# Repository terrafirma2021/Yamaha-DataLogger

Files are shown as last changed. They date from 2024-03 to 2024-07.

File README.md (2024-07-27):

### Yamaha DataLogger
ESP32 s3 BLE Yamaha Datalogger

#### Description:
- The Yamaha DataLogger is an ESP32-S3 based device designed to convert k-line data into Canbus ODB2 standard, using ELM327 emulation. 
 Enabling compatibility with apps like RaceChrono, Realdash, and Torque. 
- Now displays PIDS via OLED screen. 
- Now handles automatic gear ratio tuning via BLE Serial "Gears", (using gipro gear indicators learn function approach). Place bike on centre stand and cycle though the gears 

#### updates:
- Migrated NVS to spiffs
- gear ratios persist on cold boot / auto load on startup
- added simple temrinal menu via serial/ble
- All serial/ble serial commands are simultaneously mirrored.
- General tidy up
- Migrated send/response commands

#### Added Files:
- Added Ecu Emulator for testing
- Added Torque app PID.csv
- Wokwi PCB Design
- My custom PCB build
- L9637d pinout
- Realdash XML (Plug and play)
- racechrono.rcz file
- 3d Printed Case STL + Photos
- 3D printed case with switch mount (switch can be found below):
- https://www.amazon.co.uk/dp/B01N367QLZ

#### Added OLED Support:
- 0.96" I2C

#### Supported PIDs:
- RPM
- Speed
- Error code
- Coolant Temp
- Gear
- MCU Temp
- CPU Freq
- Ram Free
- Top Speed
- MCU Uptime seconds

#### Requirements:
To build this project, you will need the following components:
- L9637D
- <strike>510 pull-up resistor</strike> Not needed for RX
- Level conversion components
- Due to ESP32 startup time, an external power supply switch will be required to enable esp32 to start before the ecu! This saves re-writing the codebase.

#### Additional Information:
- It's possible to pozi-tap the loom for other sensor data not sent via the k-line.
- Wokwi circuit design: https://wokwi.com/projects/391712730296045569
- Thingverse link here: https://www.thingiverse.com/thing:6560376

#### Big thanks to:
- [TriB](https://github.com/HerrRiebmann) For the L9637D's and LOTS of wise advice from an ECU VET :) 
- The Dude Discord: @skydiving123 For Schooling me alot :P  \o/
- [Unexpected Maker:](https://esp32s3.com) for the Feather S3 and support
- [RealDash](https://realdash.net/index.php)
- [Race Chrono](https://racechrono.com)

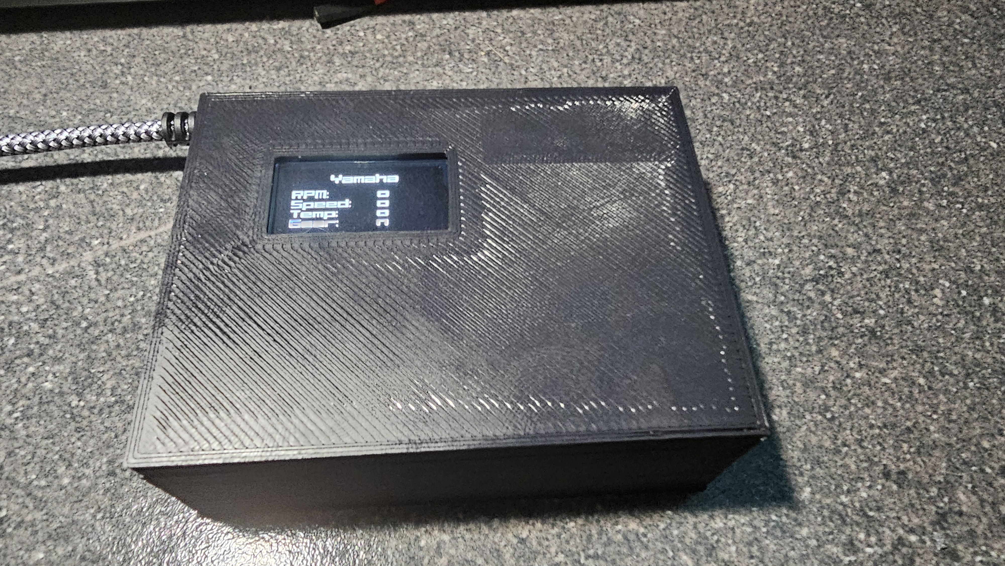
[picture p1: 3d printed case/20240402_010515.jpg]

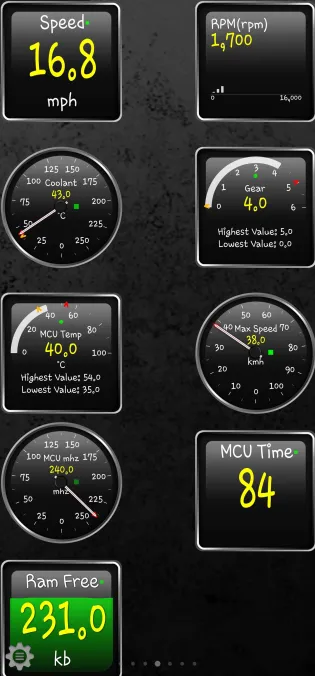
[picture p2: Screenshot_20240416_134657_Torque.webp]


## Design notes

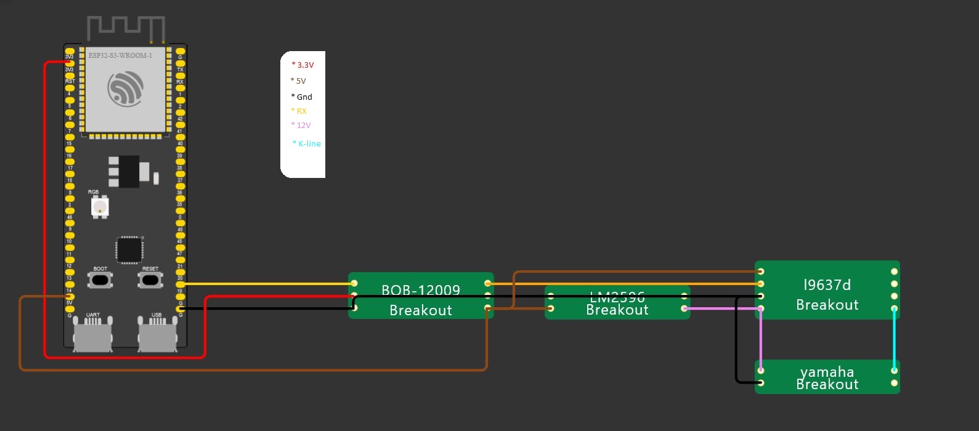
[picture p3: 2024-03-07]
wokwi_schematic.JPG

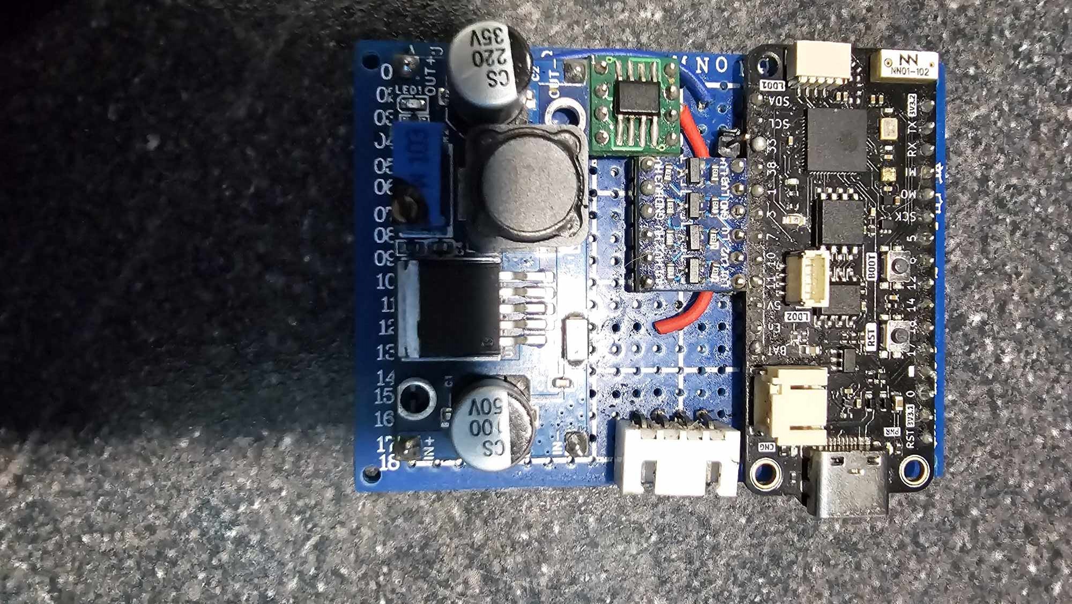
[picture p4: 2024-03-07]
My_PCB.jpg

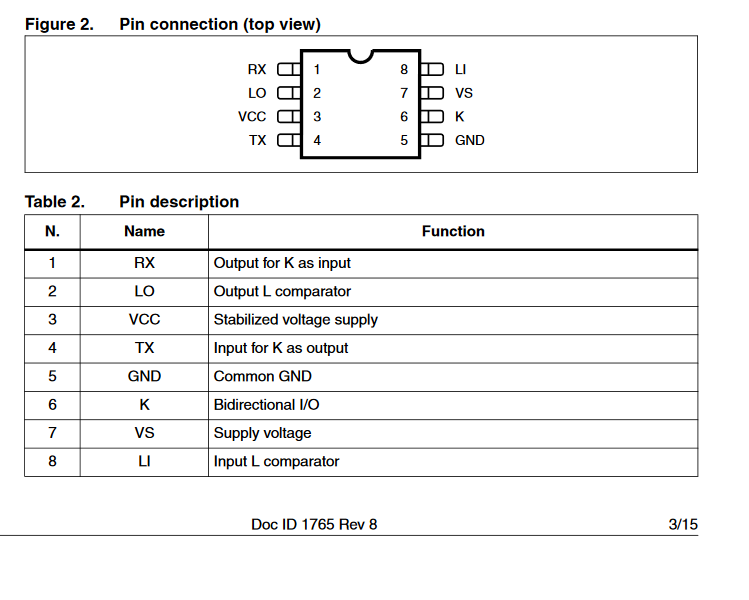
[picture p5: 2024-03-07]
L9637d.PNG

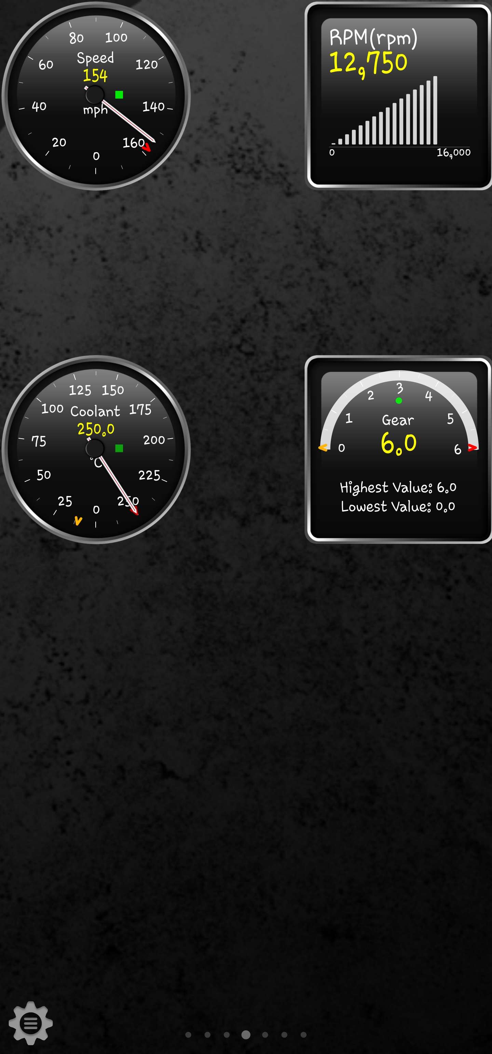
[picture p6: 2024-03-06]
Screenshot_20240306_113752_Torque.jpg

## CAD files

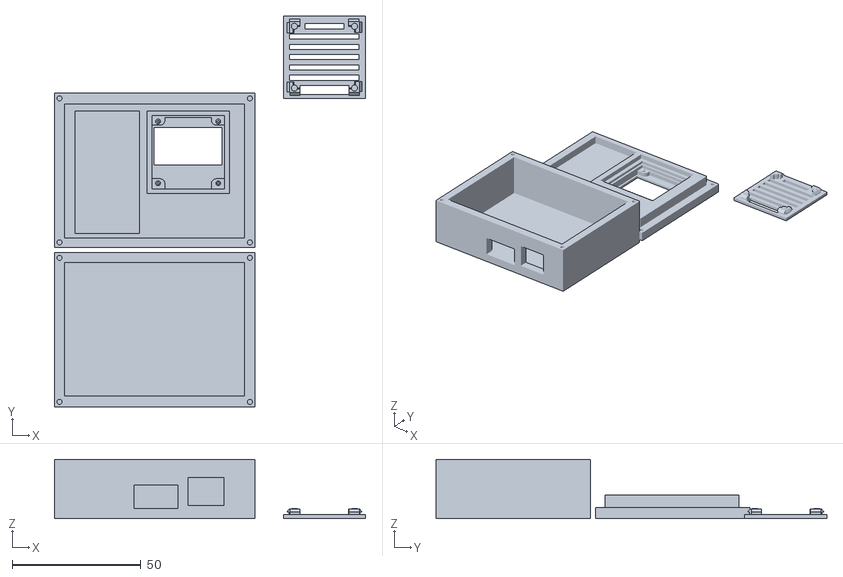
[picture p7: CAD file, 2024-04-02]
3d printed case/YDS Box.stl
121.0 x 152.0 x 23.0

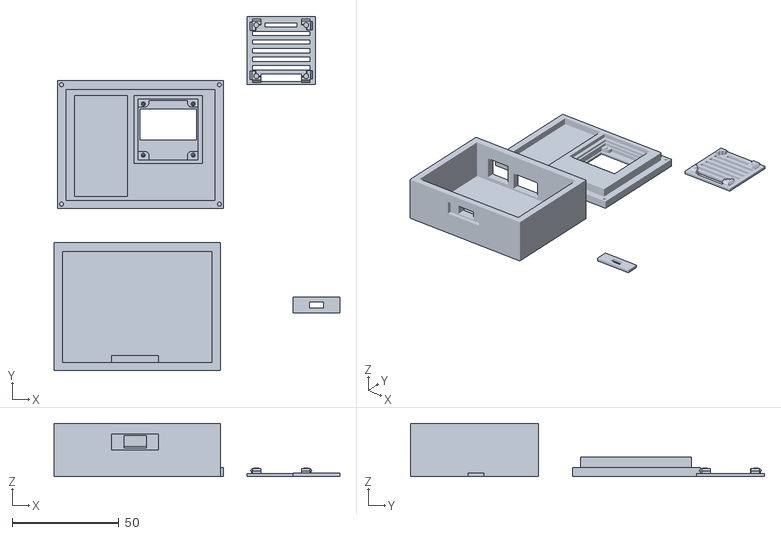
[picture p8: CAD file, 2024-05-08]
YDS BOX v3.stl
134.0 x 166.0 x 25.0

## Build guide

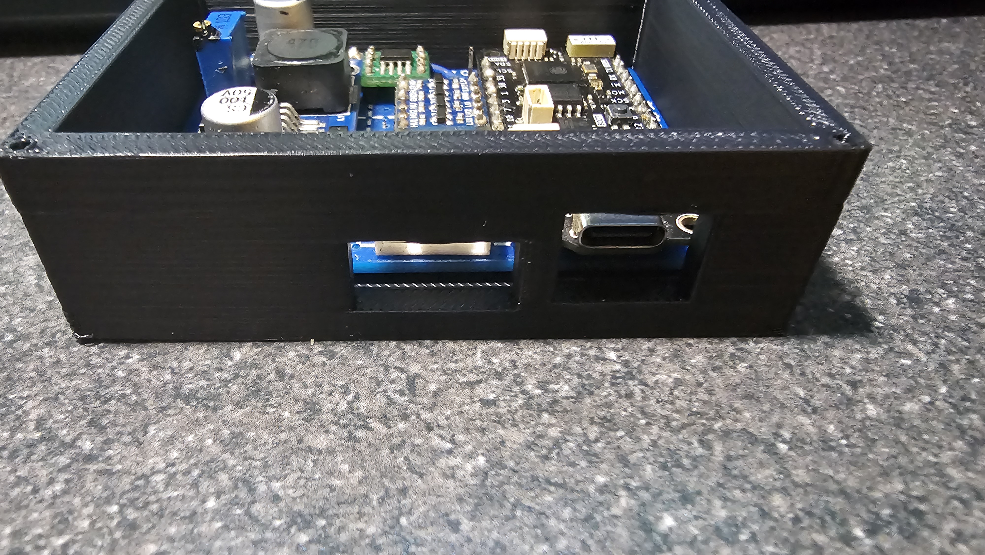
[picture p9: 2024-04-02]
3d printed case/20240402_002836.jpg

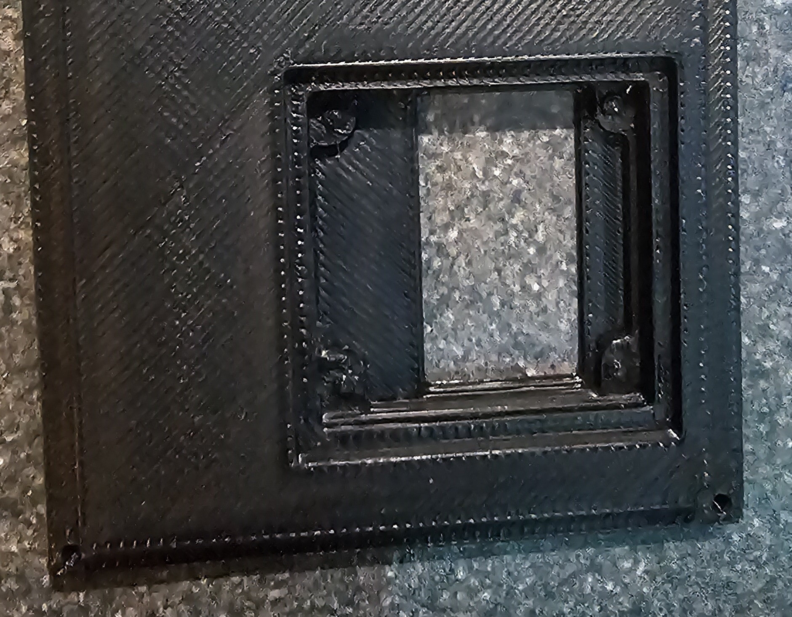
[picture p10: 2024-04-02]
3d printed case/20240401_235949.jpg

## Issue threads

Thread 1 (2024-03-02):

Schema to setup project

slowas, 2024-03-02:
Hey, I' am very intresting in your project can' you share schematic to setup this code?

terrafirma2021, 2024-03-05:
Hi yes, I will make a schematic soon, I am currently finishing up on my code.

I intend to rewrite the code to support a USB KKL Cable, (which I started from) meaning that any device with a USB host will natively be able to work from the KKL cable. This will help others who may not be able to solder, to plug in a cable :)

terrafirma2021, 2024-03-07:
@slowas Please see my main repo,, i have attached a wokwi schematic with colour coding for you. Here is the URL to the Wowki design, please be aware that I have adjusted the pinout order for clear understanding. When you build your own design, only cross over the data lines once!
https://wokwi.com/projects/391712730296045569

Closed 2024-03-07.

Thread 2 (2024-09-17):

Can't connect to ECU

VovaN60, 2024-09-17:
Hello Dear,

I don't see any contacts in your profile.
Sorry but that's why i am creating an issue.

I am working on GPS datalogger project for a few years now. And trying to adapt it to Yamaha protocol.
Tried alot with no success. Need your support.

Kindly contact me.
vovenracer@gmail.com

terrafirma2021, 2024-09-21:
HI, please upload a photo of your pcb, i will help you

terrafirma2021, 2025-03-09:
Hi, closing this issue as i have not heard back in some time, thanks

Closed 2025-03-09.

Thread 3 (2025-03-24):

Not quite pulling the right data from the packets

threepotMR2, 2025-03-24:
Firstly this is amazing! Thank you for putting this on github, its wonderful tool for the Yamaha k line.

There are loads of kit cars with the yamaha R1 engine in them, if this works I'm sure there will be other guys wanting to get this built as it should pull speed, rpm etc into racechrono. I want to also implement out getting some 0-5v analogue inputs working for TPS and wideband AFR which should be very straight forward.

I've got all the hardware running - k line adapter, the level shifter etc - that was a bit of scoping fun!! Turns out the level shifters I'd bought were not pick and placed correctly.

And it sort of works, its logging, its bluetoothing etc. I'm nearly there but.......

I think there is something not right with the packet interpretation, maybe its differences of bike - this is on a 2010 YZF-R1.

The coolant value is getting mixed up with another value, it jumps from the correct value to something else.

Here is a video of the debug PID and debug RX (which is amazing that you've built the whole menu system etc!!), and the torque pro screen.

https://www.youtube.com/watch?v=PzoZdSJurxI

I'd love it if you can shed any light on it?

Thanks, Matt

threepotMR2, 2025-03-24:
Right, I've done a proper K line log... I built a little old arduino nano like this:-

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

Very simple, just 2 resistors and an optocoupler, that lets us RX data off the k-line.

Here is the log, its just ignition on, then I start and idle it, then rev it, obviously I can see the second byte is an RPM value.

[full log from k line.txt](https://github.com/user-attachments/files/19438185/full.log.from.k.line.txt)

Then I was thinking about your project, the hardware is vastly over complicated I think, it could be done just like this:-

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

Which would sit on a very small pcb just like this very easily:-

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

terrafirma2021, 2025-04-12:
HI, thanks for the updated, information, its nice to see others pick up on the project.

Its Interesting to see an alt to the Yamaha protocol,

I know there is a v1 and a v2 dash protocol for the Yamaha,

assuming that the 5 byte protocol is used ( you should also be able to check with sigrok to confirm)

the protocol is always dash request, then ecu returns,

Interesting to see the 0A request, but it may well be that the dash is requesting more information than just rpm,vss, error code, coolant temp.

When you enter into diag mode, you will see this behaviour when in a D_ sub menu section, where the menu case is returned, then you will see the value of the menu case.

i believe i have posted sigrok sniffs of the diag menu and the main menu.

your video actually appears to be doing the same approach somewhat, which is why you are seeing ( mis reads)

terrafirma2021, 2025-04-12:
01 17 00 00 42 59
05 17 00 00 2C 43
0C 17 00 00 23 3A
0D 16 00 00 01 17

05, 0c,0d are a different type of poll which i have not seen before

threepotMR2, 2025-04-12:
0C 17 00 00 "23" 3A = this is Throttle position

I have tried to alter the way your buffer handling works in your source code.

I have tried to make the buffer 6 bytes long instead, then make different "if" statements for packets that start with a different byte.

But my programming ability is poor and I have not managed to make anything that works.

terrafirma2021, 2025-04-12:
if you go into the diag menu and sniff from there the TPS value, you will know the % to byte ratio,

this is how i worked out the coolant temp sensor

this will also allow you to decode the other values to know what they are

by cycling the diag menu, you will obtain and decode the missing values from the other frames friend

threepotMR2, 2025-04-12:
TPS is easy:-

0C 16 0 0 23 39 = 14%
0C 16 0 0 3F 55 = 25%
0C 17 0 0 83 9A = 51%
0C 2C 0 0 AC D8 = 67%
0C 51 0 0 B4 5 = 70%
0C 65 0 0 A9 0E = 66%
0C 74 0 0 6E E2 = 43%
0C 8E 0 0 2B B9 = 17%
0C 89 0 0 23 AC = 14%

0 to FF = 0 to 256 = 0% to 100%

But your programming of the main.cpp....

All you do is handle the last 5 bytes of a frame, you never look at the first byte.

I have tried to change your buffer to 6 bytes, then have some if statements on the first byte.

#define ECU_BUFFER_SIZE 5

then....

else if (isIMMOHandled)
  {
    **// Ensure buffer does not exceed 5 bytes
    if (buffer.size() >= 5)
    {**
      buffer.erase(buffer.begin());
    }
    buffer.push_back(receivedByte);

    **// Process only when buffer is exactly 5 bytes**
    if (buffer.size() == 5)
    {
      bool allZero = std::all_of(buffer.begin(), buffer.end(), [](uint32_t i)
                                 { return i == 0; });

      if (!allZero)
      {
        t_buffer_item sum = std::accumulate(buffer.begin(), buffer.end() - 1, 0);
        if (sum == buffer.back())
        {
          alignedFrame(buffer);
          buffer.clear(); // Clear the buffer for the next frame
        }
      }
    }

I am totally failing to change your code to handle the packed correctly because I am a stupid idiot LOL!

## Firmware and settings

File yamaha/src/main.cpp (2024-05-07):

#include <Arduino.h>
#include <elm327command.h>
#include <BLE.h>
#include <gear.h>
#include <spifffs.h>
#include <responsecommand.h>
#include <vector>
#include <unordered_map>
#include "esp_timer.h"
#include "LCD.h"
#include <Adafruit_GFX.h>
#include <Adafruit_SSD1306.h>
#include <U8g2lib.h>
#include <iostream>
#include <string>
#include <Wire.h>
#include <numeric>
#include <SPI.h>
#include <SPIFFS.h>


// Define L9637D Pins
#define YAM_TX 1
#define YAM_RX 38

// Debug Pins
/// #define YAM_TX 12
// #define YAM_RX 33

// Define SDA and SCL pins
#define MY_SCL_PIN 15
#define MY_SDA_PIN 16

// Debug Level
extern bool Debug_RX;
extern bool Debug_TX;
extern bool Debug_PIDS;
extern bool Debug_YAM;
bool DisableBikeOff_Flag = false;

// BLE Connected bool
extern bool clientConnected;

// Time thresholds and timeouts
uint32_t Time = esp_timer_get_time() / 1000;
const uint16_t BIKE_OFF_TIMEOUT_TIMER = 5000; // 5 seconds in microseconds
uint32_t lastByteTime = 0; 

// BLE Timers
static uint32_t lastSendTimeUartTX = 0;
static uint32_t lastSendTimeUartRX = 0;
static uint32_t lastSendTimeElmTX = 0;
static uint32_t lastSendTimeElmRX = 0;
const uint16_t sendIntervalUartTX = 1;
const uint16_t sendIntervalUartRX = 2;
const uint16_t sendIntervalElmTX = 3;
const uint16_t sendIntervalElmRX = 4;

// Magic numbers
const byte DIAG_START_BYTE = 0xCD;

// Buffer sizes
#define VEHICLE_SPEED_RAW_BUFFER_SIZE 8
#define ECU_BUFFER_SIZE 5

// Yamaha RX Buffers
using t_buffer_item = uint8_t;
using t_buffer = std::vector<t_buffer_item>;
byte Vehicle_Speed_Raw_Buffer[VEHICLE_SPEED_RAW_BUFFER_SIZE];
byte ECU_Buffer[ECU_BUFFER_SIZE];

// Immo discarded bytes
static uint32_t discardedBytesCount = 0;

// Buffer indices and time variables
byte VehicleSpeedRawBufferIndex = 0;
byte ECUBufferIndex = 0;
byte IMMOIndex = 0;

// Immo flags
bool is3E = false;
bool isIMMOHandled = false;

// ECU Mode
bool NormalData = false;
bool frameEndDetected = false;
bool diagMenu = false;

// Gears
uint8_t gear_speed = 0;
uint16_t gear_rpm = 0;
bool Gear_Speed_Ready = false;
bool Gear_RPM_Ready = false;
extern bool gearLearning;
extern bool ratioReset;
extern std::vector <float> constRatios;

// Top Speed
byte MaxSpeed = 0;

// BLE Arrays
std::queue<std::string> MyCallbacks::bleUartRxQue;
std::queue<std::string> MyCallbacks::bleElmRxQueue;

// PIDS
uint16_t RPM_PID;        // RPM * 50 = RAW
uint8_t Speed_PID;       // RAW km/h
uint8_t Coolant_PID;     // Temp = -30
uint8_t Error_PID;       // Error code
uint8_t Gear_PID = 0;    // RAW 
uint8_t Temp_PID;        // MCU Temp C
uint8_t CPU_PID;         // CPU Freq mhz
uint8_t RAM_Free_PID;    // Free Ram kb
uint8_t Max_Speed_PID;   // Max Speed Reached
uint16_t MCU_Uptime_PID; // Seconds

// Function declarations
void setup();
void loop();
void mainTime();
void YamahaRX();
void processIMMOSequence(t_buffer &buffer, t_buffer_item receivedByte);
void alignedFrame(const t_buffer &buffer);
void handleDiagData(const t_buffer &buffer);
void handleNormalData(const t_buffer &buffer);
void sendResponse(const std::string &message);
void serialRX();
extern void receiveResponse(std::string message);
void handleBikeOffCondition();
void calculateRPM(t_buffer_item rpmByte);
void calculateVehicleSpeed(t_buffer_item speedByte);
void extractErrorCode(t_buffer_item Error);
void calculateCoolantTemp(t_buffer_item Temp);
void maximumSpeed();
void updateMcuPidValues();
void debugPIDS();
void toUpperCaseInPlace(std::string &str);
void trimInPlace(std::string &str);
extern void gears();
extern void menu(std::string command);
void bleTimers();
extern void loadSpiffRatios();


// Setup
void setup()
{
  Serial.begin(115200);
  Serial1.begin(16040, SERIAL_8N1, YAM_RX, YAM_TX);
  Serial.println("Yamaha ELM327 Datalogger");
  Serial.print("MCU Temperature: ");
  Serial.print(temperatureRead());
  Serial.println(" °C");
  Serial.print("CPU Frequency: ");
  Serial.print(ESP.getCpuFreqMHz());
  Serial.println(" MHz");
  Serial.print("Free Heap: ");
  Serial.print(ESP.getFreeHeap());
  Serial.println(" bytes");
  Serial.print("Max Alloc Heap: ");
  Serial.print(ESP.getMaxAllocHeap());
  Serial.println(" bytes");
  Wire.begin(MY_SDA_PIN, MY_SCL_PIN);
  u8g2.begin();
  MyCallbacks *myCallbacks = new MyCallbacks();
  bool success = Device::getInstance().start(myCallbacks);
  if (!success)
  {
    sendResponse("Failed to start BLE");
  }
  if (!SPIFFS.begin())
  {
    sendResponse("SPIFFS mount failed");
    return;
  }
  // Init the Gear ratios from the spiffs
  loadSpiffRatios();
  menu("MENU");
}

void loop()
{
  mainTime();
  bleTimers();
  handleBikeOffCondition();
  YamahaRX();
  displayData();
  serialRX();
  debugPIDS();
  updateMcuPidValues();
  gears();
}

void mainTime(){
  Time = esp_timer_get_time() / 1000;
}

void YamahaRX()
{
  static t_buffer buffer;

  if (!Serial1.available())
  {
    return;
  }

  // Update lastByteTime with esp_timer_get_time()
  lastByteTime = esp_timer_get_time() / 1000;

  // Read a byte from Serial1
  t_buffer_item receivedByte = Serial1.read();

if (Debug_YAM)
{
    std::stringstream ss;
    ss << "Yam RX: " << std::setw(2) << std::setfill('0') << std::hex << static_cast<int>(receivedByte);
    // Get the string representation without the "0x" prefix
    std::string output = ss.str().substr(2);
    sendResponse(output);
}


  // Check and handle the first byte of the IMMO sequence immediately
  if (!is3E && receivedByte == 0x3E)
  {
    is3E = true;
    buffer.push_back(receivedByte);
    sendResponse("Starting IMMO sequence.");
    return;
  }

  if (is3E && !isIMMOHandled)
  {
    // Continue handling the IMMO sequence
    processIMMOSequence(buffer, receivedByte);
  }
  else if (isIMMOHandled)
  {
    // Ensure buffer does not exceed 5 bytes
    if (buffer.size() >= 5)
    {
      buffer.erase(buffer.begin());
    }
    buffer.push_back(receivedByte);

    // Process only when buffer is exactly 5 bytes
    if (buffer.size() == 5)
    {
      bool allZero = std::all_of(buffer.begin(), buffer.end(), [](uint32_t i)
                                 { return i == 0; });

      if (!allZero)
      {
        t_buffer_item sum = std::accumulate(buffer.begin(), buffer.end() - 1, 0);
        if (sum == buffer.back())
        {
          alignedFrame(buffer);
          buffer.clear(); // Clear the buffer for the next frame
        }
      }
    }
  }
}

void processIMMOSequence(t_buffer &buffer, t_buffer_item receivedByte)
{
  // Push the received byte into the buffer
  buffer.push_back(receivedByte);

  if (buffer.size() == 61)
  {

    if (buffer.back() == 0xCD)
    {
      diagMenu = true; // Diag menu init
      buffer.clear();
      sendResponse("Diag start initiated.");
    }
    else
    {
      buffer.clear();
    }

    isIMMOHandled = true;
    sendResponse("Normal start initiated.");
  }
}

void alignedFrame(const t_buffer &buffer)
{
  // First, ensure that the buffer size is as expected.
  if (buffer.size() != 5)
  {
    return;
  }

  if (diagMenu)
  {
    handleDiagData(buffer);
  }
  else
  {
    handleNormalData(buffer);
  }
}

void handleDiagData(const t_buffer &buffer)
{
  sendResponse("Diag menu!");
}

void handleNormalData(const t_buffer &buffer)
{

  maximumSpeed();

  if (buffer.size() != 5)
  {
    return;
  }

  calculateRPM(buffer[0]);
  calculateVehicleSpeed(buffer[1]);
  extractErrorCode(buffer[2]);
  calculateCoolantTemp(buffer[3]);
}

void sendResponse(const std::string &message)
{
  // Print the message
  Serial.println(message.c_str());

  // Check for empty command
  if (message.length() == 0)
  {
    Serial.println("Empty command received.");
    return; // Exit if the command is empty
  }

  Device::getInstance().bleUartQue(message);
}

std::string serialRXBuffer;  // Buffer to accumulate characters

void serialRX() {
    // Check if the serial connection is still active
    if (!Serial) {
        return;
    }

    if (Serial.available() > 0) {  // Check if there is data to process
        char ch = Serial.read();  // Read one character from the serial

        if (ch == '\n') {  // Check if the character is a newline
            if (!serialRXBuffer.empty()) {
                receiveResponse(serialRXBuffer);  // Process the accumulated input
                serialRXBuffer.clear();  // Clear the buffer after processing
            }
        } else {
            serialRXBuffer += ch;  // Add character to buffer if not newline
        }
    }
}

void handleBikeOffCondition()
{
  // Early return if the bike off condition handling is disabled or lastByteTime is zero
  if (DisableBikeOff_Flag || lastByteTime == 0)
  {
    return;
  }
      // Get the current time in microseconds
  uint64_t timeElapsed = Time - lastByteTime; // Calculate time elapsed since the last byte received

  if (timeElapsed > BIKE_OFF_TIMEOUT_TIMER)
  {
    // Reset flags and variables related to bike off condition
    is3E = false;
    isIMMOHandled = false;
    NormalData = false;
    frameEndDetected = false;
    diagMenu = false;
    ECUBufferIndex = 0;
    lastByteTime = 0;
    Gear_PID = 0;
    Coolant_PID = 0;
    RPM_PID = 0;
    Speed_PID = 0;
    Error_PID = 0;
    // Reset Gear
    ratioArray.clear();
    sendResponse("\nBike Off Detected");
  }
}

void calculateRPM(t_buffer_item rpmByte)
{

  uint8_t RPM = rpmByte;

  // Assign the RPM value directly to RPM_PID and gear_rpm.
  RPM_PID = RPM * 50; // Correct up to 12500
  gear_rpm = RPM_PID;
}

void calculateVehicleSpeed(t_buffer_item speedByte)
{

  if (VehicleSpeedRawBufferIndex < VEHICLE_SPEED_RAW_BUFFER_SIZE)
  {
    Vehicle_Speed_Raw_Buffer[VehicleSpeedRawBufferIndex++] = speedByte;
  }

  // Check if the buffer is full.
  if (VehicleSpeedRawBufferIndex == VEHICLE_SPEED_RAW_BUFFER_SIZE)
  {
    int totalSpeed = 0;
    for (int i = 0; i < VEHICLE_SPEED_RAW_BUFFER_SIZE; ++i)
    {
      totalSpeed += Vehicle_Speed_Raw_Buffer[i]; // Accumulate speed data.
    }

    // Process the accumulated speed data.
    Speed_PID = totalSpeed;
    MaxSpeed = totalSpeed;

    gear_speed = Speed_PID;

    // Keep sync of Speed/RPM
    Gear_Speed_Ready = true;
    Gear_RPM_Ready = true;

    // Reset the buffer index to 0 for the next frame.
    VehicleSpeedRawBufferIndex = 0;
  }
}

void extractErrorCode(t_buffer_item Error)
{
  Error_PID = Error;
}

void calculateCoolantTemp(t_buffer_item Temp)
{
  Coolant_PID = Temp - 30;
}

void maximumSpeed()
{
  static byte topSpeed = 10; // Static variable initialization
  if (Speed_PID > topSpeed)
  {
    topSpeed = Speed_PID; // Update if the current Speed_PID is greater
    Max_Speed_PID = topSpeed;
  }
}

void updateMcuPidValues()
{
  static uint32_t lastUpdateTime = 0;
  const uint16_t updateInterval = 500;        // Interval in milisecomds

  // Check if the update interval has passed
  if ((Time - lastUpdateTime) >= updateInterval)
  {
    // Update the last update time to the current time
    lastUpdateTime = Time;
    MCU_Uptime_PID = Time / 1000; // Convert milliseconds to seconds

    // Read the current temperature and update the temperature PID value
    float temperature = temperatureRead();
    Temp_PID = temperature;

    // Update CPU frequency PID value
    CPU_PID = ESP.getCpuFreqMHz();

    // Update free RAM PID value, converting bytes to kilobytes
    RAM_Free_PID = ESP.getFreeHeap() / 1024;
  }
}

void debugPIDS()
{
  if (Debug_PIDS)
  {
    sendResponse(std::string("RPM: ") + std::to_string(RPM_PID) + "\n" +
                 "Vehicle Speed: " + std::to_string(Speed_PID) + "\n" +
                 "Current Gear: " + std::to_string(Gear_PID) + "\n" +
                 "Coolant Temp: " + std::to_string(Coolant_PID) + "\n" +
                 "Error Code: " + std::to_string(Error_PID) + "\n" +
                 "MCU Temp: " + std::to_string(Temp_PID) + "\n" +
                 "CPU Mhz: " + std::to_string(CPU_PID) + "\n" +
                 "Ram Free: " + std::to_string(RAM_Free_PID) + "\n" +
                 "Max Speed: " + std::to_string(Max_Speed_PID) + "\n" +
                 "MCU Uptime Seconds: " + std::to_string(MCU_Uptime_PID) + "\n");
  }
}

void toUpperCaseInPlace(std::string &str)
{
  for (auto &c : str)
  {
    // Convert each character to uppercase
    c = std::toupper(static_cast<unsigned char>(c));
  }
}

void trimInPlace(std::string &str)
{
  // Lambda function to check if a character is not a whitespace
  auto notSpace = [](int ch)
  {
    return !std::isspace(static_cast<unsigned char>(ch));
  };

  // Find the first non-whitespace character
  auto start = std::find_if(str.begin(), str.end(), notSpace);
  // Erase leading whitespace
  str.erase(str.begin(), start);

  // Find the last non-whitespace character
  auto end = std::find_if(str.rbegin(), str.rend(), notSpace).base();
  // Erase trailing whitespace
  str.erase(end, str.end());
}


void bleTimers()
{

  // Existing UART TX processing
  if (Time - lastSendTimeUartTX >= sendIntervalUartTX)
  {
    Device::getInstance().bleUartSend();
    lastSendTimeUartTX = Time;
  }

  // Elm TX queue processing
  if (Time - lastSendTimeElmTX >= sendIntervalElmTX)
  {
    Device::getInstance().bleElmSend();
    lastSendTimeElmTX = Time;
  }

  // Existing UART RX processing
  if (Time - lastSendTimeUartRX >= sendIntervalUartRX)
  {
    MyCallbacks::processUartRXQueue();
    lastSendTimeUartRX = Time;
  }

  // NEW: Elm RX queue processing
  if (Time - lastSendTimeElmRX >= sendIntervalElmRX)
  {
    MyCallbacks::processElmRxQueue();
    lastSendTimeElmRX = Time;
  }
}

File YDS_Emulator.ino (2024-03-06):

#include <Arduino.h>

#define STARTUP_BUFFER_SIZE 55
uint8_t Startup_buf[STARTUP_BUFFER_SIZE];

bool startupSent = false;
bool ecuRespondReady = false;

// Default values for RPM, Speed, and Coolant Temperature
uint8_t rpm = 0;
uint8_t speed = 0;
uint8_t errorCode = 0;
uint8_t coolantTemp = 0;

// Fake IMMO/ Normal Boot mode
void sendStartupMessages() {
  if (!startupSent) {
    // Fill Startup_buf with startup messages
    Startup_buf[0] = 0x3E; // 0x3E message

    // Fill IMMO sequence bytes (all but the last byte)
    for (int i = 1; i < STARTUP_BUFFER_SIZE - 1; ++i) {
      Startup_buf[i] = 0x00; // Default value set to 0x00
    }

    // Set the last byte to 0xFE
    Startup_buf[STARTUP_BUFFER_SIZE - 1] = 0xFE;

    // Send Startup_buf over Serial1
    Serial1.write(Startup_buf, STARTUP_BUFFER_SIZE);
    //Serial.println("Startup messages sent");
    startupSent = true;
    ecuRespondReady = true; // Set ECU response ready flag
  }
}

void ecuRespond() {
  static unsigned long lastResponseTime = 0;
  const unsigned long responseInterval = 7; // Interval for sending the ECU response in milliseconds

  unsigned long currentMillis = millis();
  // Check if enough time has elapsed since the last response and the ecuRespondReady flag is set
  if (ecuRespondReady && currentMillis - lastResponseTime >= responseInterval) {
    // Fill ecuRespond_buf with ECU response
    uint8_t ecuRespond_buf[6];
    ecuRespond_buf[0] = 0x01;
    ecuRespond_buf[1] = rpm; // Update RPM value
    ecuRespond_buf[2] = speed; // Update Speed value
    ecuRespond_buf[3] = errorCode; // Update Error Code value
    ecuRespond_buf[4] = coolantTemp; // Update Coolant Temperature value

    // Calculate checksum
    uint8_t checksum = ecuRespond_buf[1] + ecuRespond_buf[2] + ecuRespond_buf[3] + ecuRespond_buf[4];
    ecuRespond_buf[5] = checksum;

    // Send ecuRespond_buf over Serial1
    Serial1.write(ecuRespond_buf, sizeof(ecuRespond_buf));

    // Update lastResponseTime
    lastResponseTime = currentMillis;

    // Introduce a delay of 7 milliseconds
    delay(responseInterval);
  }
}

void setup() {
  Serial.begin(115200);
  // Print the message along with the initial values for RPM, Speed, Error Code, and Coolant Temp. 
  Serial.println("Hi, Pick your ECU Values, in decmimal with spaces between values then press enter to dynamically change them\n"
                 "RPM: 0\n"
                 "Speed: 0\n"
                 "Error Code: 0\n" // Added Error Code line
                 "Coolant Temp: 0");
  Serial1.begin(16040, SERIAL_8N1, 7, 8); // Using pins 7 (RX) and 8 (TX) for Serial1
}

void loop() {
  sendStartupMessages(); // Run once at the beginning
  ecuRespond(); // Run continuously after startup messages are sent

  if (Serial.available() > 0) {
    // Read user input from the serial monitor
    String userInput = Serial.readStringUntil('\n');

    // Convert the strings to integers
    int rpmInput, speedInput, errorCodeInput, coolantTempInput;
    sscanf(userInput.c_str(), "%d %d %d %d", &rpmInput, &speedInput, &errorCodeInput, &coolantTempInput);

    // Convert the values to uint8_t and update RPM, Speed, Error Code, and Coolant Temperature values
    rpm = (uint8_t)rpmInput;
    speed = (uint8_t)speedInput;
    errorCode = (uint8_t)errorCodeInput;
    coolantTemp = (uint8_t)coolantTempInput;

    // Print updated values
    Serial.print("RPM: ");
    Serial.println(rpm * 50);
    Serial.print("Speed: ");
    Serial.println(speed * 8);
    Serial.print("Error Code: ");
    Serial.println(errorCode);
    Serial.print("Coolant Temp: ");
    Serial.println(coolantTemp);
  }
}

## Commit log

2024-01-19 Update yds.h
    Added Fully customizable Gear ratio calculator,
2024-01-20 Updated gear function yds.h
2024-01-21 Update yds.h Gear Finished
2024-03-06 Torque Yamaha PIDS
    [YamahaTorquePids.csv]
2024-03-07 Update main.cpp
    Update Gear Ratio
    Use nvs storage
2024-03-07 Fixed Uart
2024-03-07 Added wokwi PCB design
2024-03-24 fixed temperatureRead Watchdog
2024-03-25 V2 torque pids
    Using the 0x10xx PID address space, giving uninterrupted PID Range
    [TorqueBHPexportedPIDsv2.csv]
2024-03-26 Migrated ble uart RX/serial RX for commands
2024-03-30 Update main.cpp
    Removed debug print
    Serial.print("Speed_PID > topSpeed");
2024-05-05 fixed pids not resetting
    Bug fix:
    PIDS were not reset when bike off
    [main.cpp]
